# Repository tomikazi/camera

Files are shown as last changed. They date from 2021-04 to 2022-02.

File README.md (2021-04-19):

# Overview
The project provides a high-quality and low-latency video stream using Raspberry Pi HQ camera while allowing control of 
the camera orientation on pan & tilt axes. The video stream can be viewed using any modern browser or mobile device.
The camera orientation can be controlled using several different means. On mobile devices, it can be controlled using
touch swipe gestures or by moving the mobile device in 3D space. On desktop or laptop computers, the keyboard or mouse
drag gestures can be used.



The project is an adaptation of the [131/h264-live-player](https://github.com/131/h264-live-player) project. It differs
from the original project in number of ways, with the most important distinction being that the camera code is structured
as a client that connects to a broker, which is capable of brokering connections to multiple cameras and allows
multiple viewers to view the same camera.

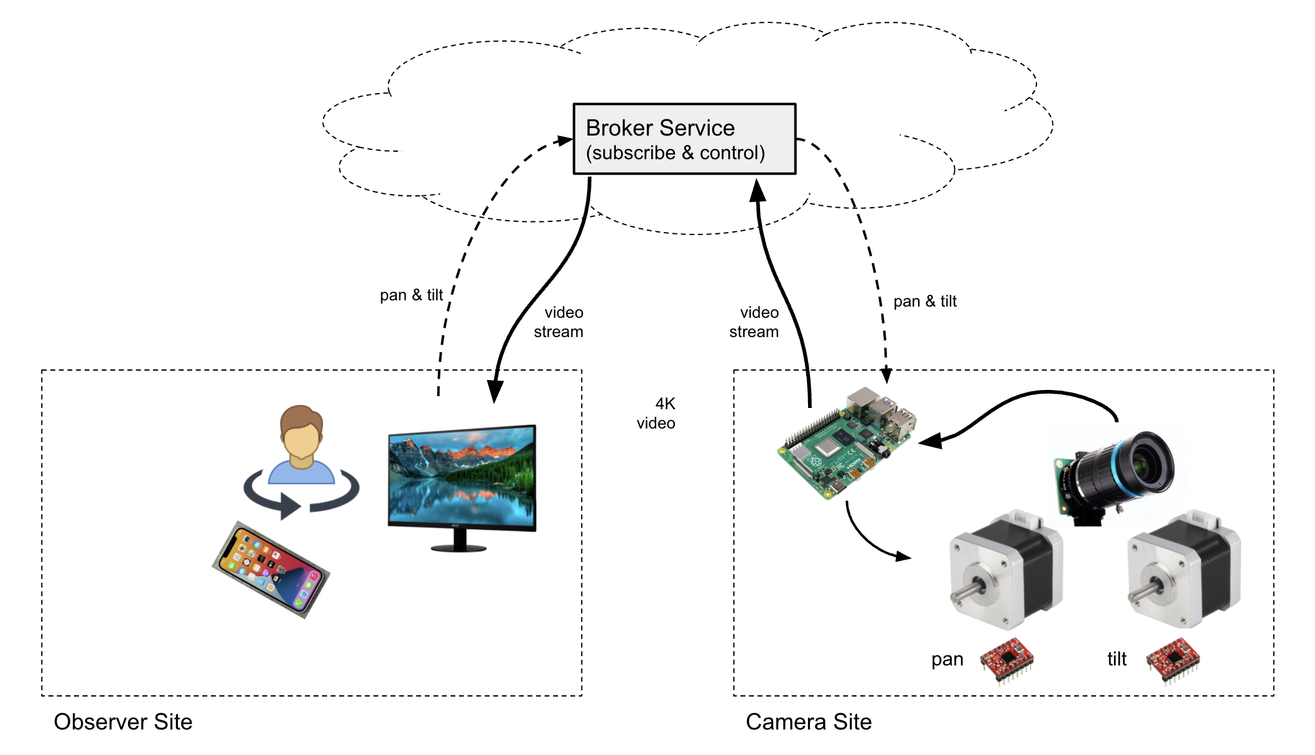
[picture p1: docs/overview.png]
Overview


This arrangement is better suited for deployment of cameras behind firewalls.

The video stream from the camera can be viewed on any modern browser. The pan/tilt can be controlled using several 
different means.

* Using mouse click-and-drag or tap-and-drag on touch devices
* Using arrow keyboard keys and other keyboard short-cuts  
* Using mobile device motion - works for iOS devices and select Androids that support `DeviceMotionEvent` Web API
    * Note that this requires the broker to use HTTPS

The pan and tilt mechanism uses A4988 stepper drivers and NEMA 17 motors to move about a Raspberry Pi HQ camera.
The current mount design allows for -180/+180 degrees on pan axis and -50/+50 degrees on tilt axis. Two hall-effect
sensors are used as limit sensors to allow for auto-homing the mount.

Note that this adaptation mangles the original by removing the alternate forms of streaming, instead focusing
solely on supporting the `raspvid` live stream.

# Installation of Broker Software
The broker is required as it is the only means of acquiring the video stream. For simple setup, it can be installed on
the same Raspberry Pi as the camera software. 

```
# Install or update the camera broker software
curl -s https://raw.githubusercontent.com/tomikazi/camera/master/tools/install-broker.sh | sh

# Setup the camera broker software to run as a daemon
curl -s https://raw.githubusercontent.com/tomikazi/camera/master/tools/install-broker-service.sh | sudo sh
```

Once started, the broker will listen on port 6000 for incoming WebSocket connections from the cameras and on port 5000 
for incoming HTTP requests and WebSocket connections from viewers. To expose HTTPS, it's probably easiest to use Apache 2
and setup redirect using URL re-writing. (_TODO: Add docs on this_)

# Installation of Camera Software
Use the following steps to install or update the camera software:

```
# Install or update the camera software
curl -s https://raw.githubusercontent.com/tomikazi/camera/master/tools/install-camera.sh | sh

# Setup the camera software to run as a daemon
curl -s https://raw.githubusercontent.com/tomikazi/camera/master/tools/install-camera-service.sh | sudo sh -s CAMERA-NAME [BROKER-URL]
```

Once started, the software will trigger auto-homing sequence and attempt WebSocket connection on port 6000 to the broker.
After the connection is established, the `raspivid` will be spawned and its video stream will be sent over the WebSocket
to the broker, from where it can be sent to the current viewers, be recorded or processed in some manner.

# Simple Token Authorization
The broker supports a simple token-based authorization scheme that allows securing access to the camera streams so that
only the users that know the camera name and a valid access token can access the video stream.

To enable the scheme, create a `tokens` file in the directory where the broker is installed. The format of the file
is as follows:

```
# userName: cameraName token
tom: FrontYard c11559d8-e91c-4140-85f0-9e14b4744e7e
tom: BackYard 329f1a1b-5c8d-40ab-9148-434f84312821
tom: Driveway 7a247b22-7bd8-4b27-8e1c-404fea90b615
guest: FrontYard 4ceb02b3-a0e9-4989-b1ff-72c3aac973ae
guest: Driveway a5217204-133d-4b39-900f-2222c962b535
```
The token is expected to be the standard 36 character UUID (see `uuidgen`). Presently, the user name is not used for
anything other than token management via the provided `ptcam-auth` script, which has the following usage:

```
usage: ptcam-auth <camera> list
       ptcam-auth <camera> <name>
       ptcam-auth <camera> grant <name>
       ptcam-auth <camera> revoke <name>
```

# Launching Viewer
To view a particular camera video stream, simply connect to the broker URL on port 5000 and specify the camera name and 
if security is required, the camera token, e.g.:

```
http://192.168.1.79:5000/camera/?id=FrontYard&t=c11559d8-e91c-4140-85f0-9e14b4744e7e
```

This will provide the web-page with the video stream canvas. The following is an example of the GUI when viewed on an
iOS device and with the camera positions shortcut menu activated:

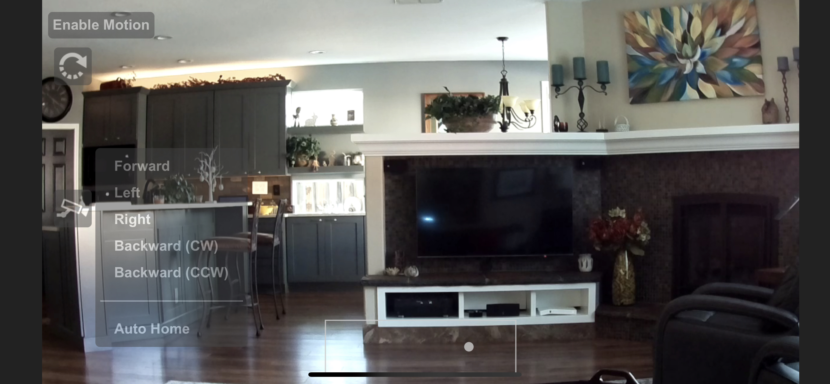
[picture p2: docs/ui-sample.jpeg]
Camera UI


The pan/tilt position and range indicator box is shown at the bottom and will be visible only when the camera is in motion.
You can see a brief [demo of the camera operation on YouTube](https://youtu.be/4mN1LiofYqg).

# REST API
The broker also supports a simple [REST API](/docs/api.md) using which other applications can query and control the remote cameras.

# Design
Additional design documentation for the 3D-printed mount, custom PCB and overall assembly can is available in the [Design](docs/design.md) section

# Credits to the original h264 project authors
* [131](mailto:131.js@cloudyks.org)
* [Broadway](https://github.com/mbebenita/Broadway)
* [urbenlegend/WebStreamer](https://github.com/urbenlegend/WebStreamer)

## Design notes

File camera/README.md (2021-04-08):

# Overview

This is an adaptation of the original h264 video player to provide a real-time (or at least low-latency) 
video stream a camera on a pan/tilt mount to a browser-based viewer. The viewer can be a mobile device
which when physically moved will result in corresponding motions of the pan/tilt mount. Alternatively,
when viewed from a computer or other devices that do not support `DeviceMotionEvent` Web API the user
can control pan/tilt by dragging the orientation indicator within the pan/tilt range box.

This adaptation mangles the original by removing the alternate forms of streaming, instead focusing
directly only on the `raspvid` live stream.  The pen tilt mechanism uses A4988 stepper drivers to mount 
and move about a Raspberry Pi HQ camera.

# Motivation
_The following are the original notes._

This is a very simple h264 video player (that can run on live stream) for your browser.
You might use this with raspicam raw h264 stream.
This is a player around [Broadway](https://github.com/mbebenita/Broadway) Decoder, with very simple API.
NAL unit (h264 frames) are split on the server side, transported using websocket, and sent to the decoded (with frame dropping, if necessary)




# History
* I was targetting a real-time camera video feedback (no audio/surveillance cam) in the browser
* There is no solution for "real time" mp4 video creation / playback (ffmpeg, mp4box.js, mp4parser - _boxing_ _takes_ _time_)
* Media Source Extension is a dead end (mp4 boxing is far too hard to re-create on the client side)
* [Broadway](https://github.com/mbebenita/Broadway) provide the crazy emscripten/asm build of a h264 decoder accelerated by webGL canvas
* Here is all the glue we need, enjoy ;-)

# Installation/demo
```
git clone git@github.com:131/h264-live-player.git player
cd player
npm install

node server-rpi.js    # run on a rpi for a webcam demo
node server-static.js # for sample video (static) file delivery
node server-tcp.js    # for a remote tcp (rpi video feed) sample
node server-ffmpeg    # usefull on win32 to debug the live feed (use ffmpeg & your directshow device / webcam) 

# browse to http://127.0.0.1:8080/ for a demo player

```

# Recommendations
* Broadway h264 Decoder can only work with **h264 baseline profile**
* [**Use a SANE birate**](https://www.dr-lex.be/info-stuff/videocalc.html)
* Browserify FTW
* Once you understand how to integrate the server-side, feel free to use [h264-live-player](https://www.npmjs.com/package/h264-live-player) npm package in your client side app (see vendor/)
* Use [uws](https://github.com/uWebSockets/uWebSockets) (instead of ws) as websocket server

# Credits
* [131](mailto:131.js@cloudyks.org)
* [Broadway](https://github.com/mbebenita/Broadway)
* [urbenlegend/WebStreamer](https://github.com/urbenlegend/WebStreamer)

# Keywords / shout box
raspberry, mp4box, h264, nal, raspivid, mse, media source extension, iso, raspicam, bitrate, realtime, video, mp4, ffmpeg, websocket, ws, socket.io "Let's have a beer and talk in Paris"

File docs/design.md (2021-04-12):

# Design 

## BOM
The following list of materials is required to assemble the camera setup:

* Raspberry Pi 4B
* Raspberry HQ Camera
* 30-50cm Raspberry Camera ribbon cable
* 1 NEMA 17 pancake motor for tilt axis
* 1 NEMA 17 motor for pan axis
* 2 A4988 stepper drivers
* 12V 3-5Amp power supply
* Buck converter (for 12V DC to 5V DC)
* 2 hall effect sensors (for limit switches)
* 2 10K resistors (for limit switches)
* 2 6mm neodymium magnets (for limit switches)
* 3D printed mount (Fusion 360 & STL files available below)
* Custom driver board and header board (Eagle and Gerber files available below)
* 13 pixel long WS2812B 60/m strand (for LED illumination and viewer indicator)    
* ~1m shielded 28AWG 3-wire cable (for limit switch cables)
* ~10cm 10-wire ribbon cable (for driver board to header board connection)
* 2 x ~60cm 4-wire stepper motor cables (may come with NEMA motors)
* ~70cm of ¼ nylon braided cable sleeving
* 4x M2.5x3-4mm screws (for securing buck converter and driver board)
* 8x 12-14mm rubber feet (4 for enclosure and 4 fo camera base)

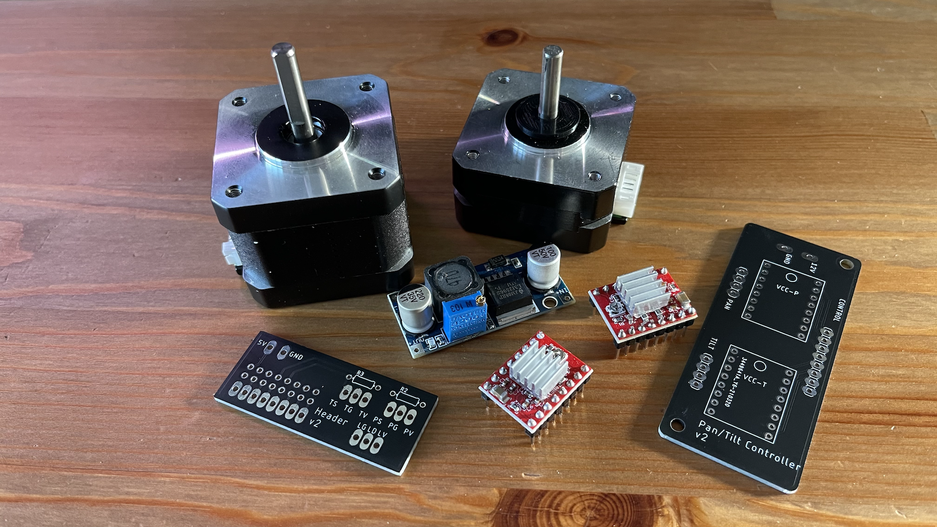
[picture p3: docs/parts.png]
Parts


## Mount and Enclosure Design
The enclosure case and the various parts of the mount itself were all custom designed from scratch using Autodesk Fusion 360. 
The objective was to make it as simple and modular as possible, while also making it reasonably compact.

The following is a list of parts together with links to the STL and the original Fusion design files:

#### Enclosure - [Fusion 360 File](../design/fusion360/PanTiltEnclosure%20v17.f3z)
* Enclosure bottom
* Enclosure top

#### Mount Assembly] - [Fusion 360 File](../design/fusion360/PanTiltMechanism%20v32.f3d)
* Pan motor mount
* Tilt motor mount
* Camera mount
* Camera plate
* Camera back plate ([design from Thingiverse](https://www.thingiverse.com/thing:4540545))
* Camera back clip
* Pan axle washer

## Electronics
A pair of simple PCBs was designed to allow for relatively simple assembly. The boards were designed using Autodesk Eagle.
Below are links to their schematic and board design files for Autodesk EAGLE:

The two boards are:
* Stepper Driver board for housing the two A4988 stepper drivers - [PCB](../design/eagle/PanTiltCtlBoard.brd) - [Schematic](../design/eagle/PanTiltCtlBoard.sch)
    * +12V/GND pads
    * 2 A4988 drivers (pan/tilt)
    * 8-pin header for harness connection to the Raspberry Pi header board

* Header break-out board for connecting to the top 16 GPIO pins of the Raspberry Pi - [PCB](../design/eagle/PanTiltHeader.brd) - [Schematic](../design/eagle/PanTiltHeader.sch)
    * 8 pads for harness interconnect with the stepper driver
    * +5V/GND to power Raspberry Pi
    * +3V3/GND/DATA pads for pan limit switch
    * +3V3/GND/DATA pads for tilt limit switch
    * +5V/GND/DATA pads for LED strip
  
The design folder also has ZIP files for ordering the PCBs on JLCPCB.

## Wiring Harnesses

* Motor Cables
    * Tilt: 56cm
    * Pan: 39cm
* Limit Sensor Cables
    * Tilt: 48cm
    * Pan: 25cm
* Sleeves for Cables
    * Tilt: 44cm
    * Pan: 20cm
* Header Ribbon Cable (8-wide)
    * 10cm
* LED Cable (5V/GND/Data)
    * 35cm

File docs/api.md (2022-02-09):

# REST API

Other applications can use the following REST API to query and control the remote cameras.

* `GET /camera/api/cameras`
    * returns array of currently registered camera names
* `GET /camera/api/viewers`
    * returns array of objects with camera name and the viewer remote address
* `GET /camera/api/:camera`
    * returns current camera position and any remote viewers
* `GET /camera/api/:camera/snapshot`
    * takes a snapshot and returns PNG image data
* `GET /camera/api/:camera/recordings`
    * returns an array of current recording files
* `GET /camera/api/:camera/recordings/:recording`
    * returns the specified recording as raw H.264 file
* `PUT /camera/api/:camera`
    * issues command to the specified camera, `setHome`, `moveTo`, `moveBy`, `snap`, `startRecording`, `stopRecording`
    * `moveTo` takes either `pos` set to `home`, `F`, `L`, `R`, `U`, `D`, `UL`, `UR`, `DL`, `DR` or `pan` and `tilt` coordinates
       * `duration` specifies number of milliseconds for the move to take
       * `ease` can be set to `linear`, `quad` or `cubic` to for specific easing function; default is `quad`
    * `moveBy` takes `pan` and `tilt` steps relative to current position
    * `setHome` records the current position as the default home
    * `startRecording`/`stopRecording` starts/stops recording of video to disc
* `DELETE /camera/api/:camera/:viewerIP`
    * disconnects all viewers from the specified IP address on the given camera; this can be used
      after revoking a token
      
## Authorization
If token authorization is enabled, the HTTP request must have the `token` header populated
with a valid camera token. Any camera token can be used to obtain the list of cameras or the list of viewers,
but any camera-specific request must have camera-specific `token` provided.

# Examples
The following are a few examples of how one might use the `curl` command to issue API requests:
```
# Get list of all cameras
curl -H 'Content-type: application/json' -H 'token: 340d1b94-9bd4-893f-49ef-4c772132ce06' \
    http://broker.local:5000/camera/api/cameras
["Driveway", "FrontYard", "BackYard"]

# Get information about front yard camera
curl -H 'Content-type: application/json' -H 'token: 340d1b94-9bd4-893f-49ef-4c772132ce06' \
    http://broker.local:5000/camera/api/FrontYard
{
  "camera": "FrontYard",
  "viewers": [
    "::ffff:192.168.1.71"
  ],
  "pos": {
    "pan": -438,
    "tilt": 219
  }
}

# Pan all the way to the right position; tilt level at 0; take 1 second and use cubic easing function to govern the move
curl -H 'Content-type: application/json' -H 'token: 340d1b94-9bd4-893f-49ef-4c772132ce06' \
    -X PUT http://broker.local:5000/camera/api/FrontYard -d '{ "cmd": "moveTo", "pos": "R", "duration": 1000, "ease": "cubic" }'

# Pan to specific coordinates in 500ms using default easing function
curl -H 'Content-type: application/json' -H 'token: 340d1b94-9bd4-893f-49ef-4c772132ce06' \
    -X PUT http://broker.local:5000/camera/api/FrontYard -d '{ "cmd": "moveTo", "pan": -50, "tilt": 10, "duration": 500 }'

# Move left (counter-clockwise) and upward relative to the current orientation
curl -H 'Content-type: application/json' -H 'token: 340d1b94-9bd4-893f-49ef-4c772132ce06' \
    -X PUT http://broker.local:5000/camera/api/FrontYard -d '{ "cmd": "moveBy", "pan": -30, "tilt": 20 }'

```

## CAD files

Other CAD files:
design/fusion360/PanTiltMechanism v32.f3d

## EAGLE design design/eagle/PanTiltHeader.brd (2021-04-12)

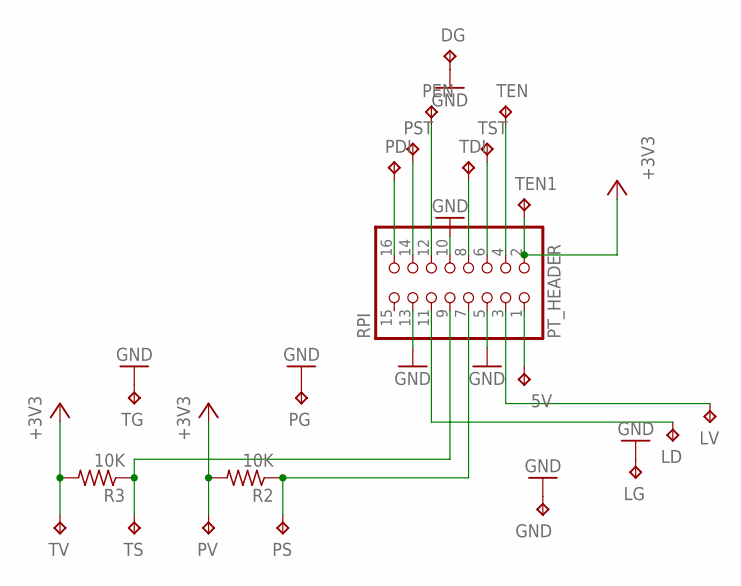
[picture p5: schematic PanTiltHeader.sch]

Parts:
5V: TPPAD1-13Y; P1-13Y
DG: TPPAD1-13Y; P1-13Y
GND: TPPAD1-13Y; P1-13Y
LD: TPPAD1-13Y; P1-13Y
LG: TPPAD1-13Y; P1-13Y
LV: TPPAD1-13Y; P1-13Y
PDI: TPPAD1-13Y; P1-13Y
PEN: TPPAD1-13Y; P1-13Y
PG: TPPAD1-13Y; P1-13Y
PS: TPPAD1-13Y; P1-13Y
PST: TPPAD1-13Y; P1-13Y
PT_HEADER: RPI; 2X08
PV: TPPAD1-13Y; P1-13Y
R2, R3: 10K; 0204/7
TDI: TPPAD1-13Y; P1-13Y
TEN, TEN1: TPPAD1-13Y; P1-13Y
TG: TPPAD1-13Y; P1-13Y
TS: TPPAD1-13Y; P1-13Y
TST: TPPAD1-13Y; P1-13Y
TV: TPPAD1-13Y; P1-13Y

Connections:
+3V3: PT_HEADER.2, PV.TP, R2.2, R3.2, TEN1.TP, TV.TP
GND: DG.TP, GND.TP, LG.TP, PG.TP, PT_HEADER.5, PT_HEADER.10, PT_HEADER.13, TG.TP
unnamed: PT_HEADER.4, TEN.TP
unnamed: PT_HEADER.6, TST.TP
unnamed: PT_HEADER.8, TDI.TP
unnamed: PT_HEADER.9, R3.1, TS.TP
unnamed: PEN.TP, PT_HEADER.12
unnamed: PST.TP, PT_HEADER.14
unnamed: PDI.TP, PT_HEADER.16
unnamed: 5V.TP, PT_HEADER.1
unnamed: LV.TP, PT_HEADER.3
unnamed: PS.TP, PT_HEADER.7, R2.1
unnamed: LD.TP, PT_HEADER.11

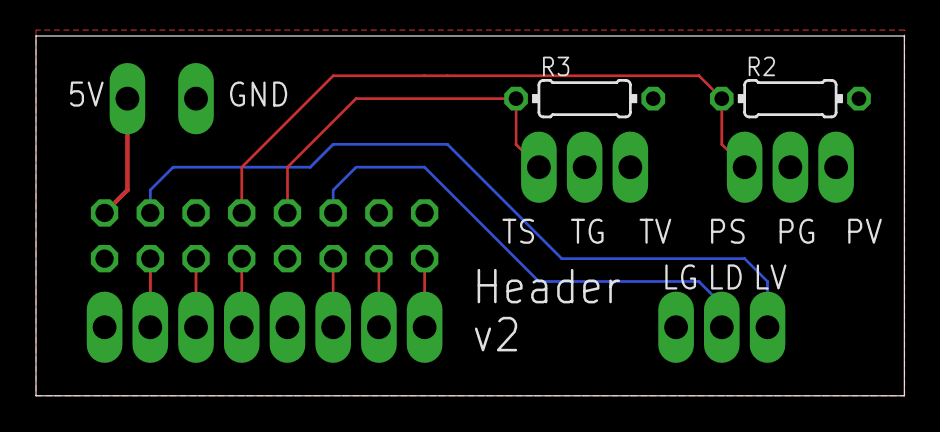
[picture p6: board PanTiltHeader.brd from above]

Board: 2 copper layers, 48.2 x 20.0 mm, 22 parts (1 on the bottom side), 13 nets.

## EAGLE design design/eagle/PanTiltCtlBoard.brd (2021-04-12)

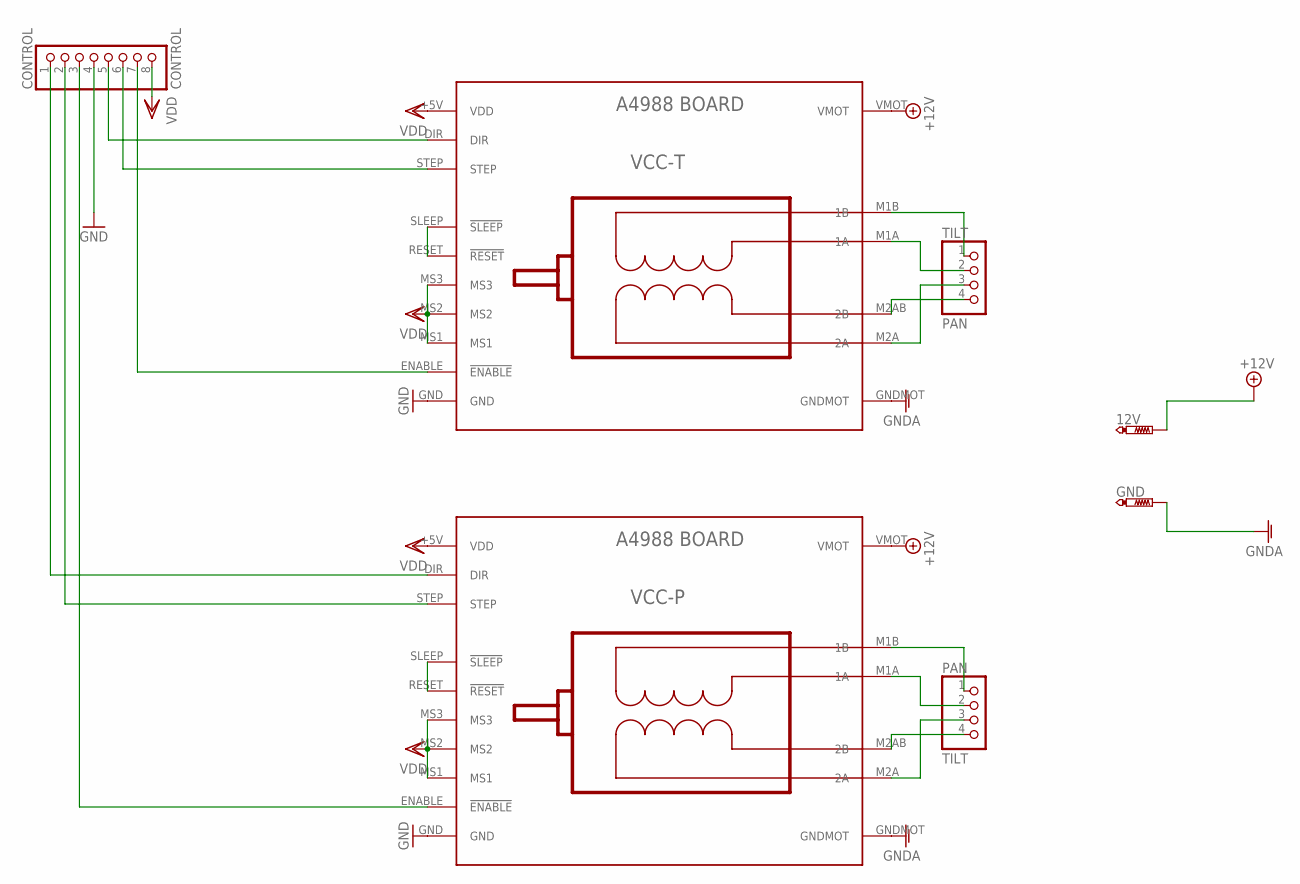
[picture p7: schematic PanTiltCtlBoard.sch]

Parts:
12V: PTR1PAD1-13Y; P1-13Y
CONTROL: CONTROL; 1X08
GND: PTR1PAD1-13Y; P1-13Y
PAN: TILT; 1X04
TILT: PAN; 1X04
VCC-P: BOARD_A4988
VCC-T: BOARD_A4988

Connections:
+12V: 12V.TP, VCC-P.VMOT, VCC-T.VMOT
GND: CONTROL.4, VCC-P.GND, VCC-T.GND
GNDA: GND.TP, VCC-P.GNDMOT, VCC-T.GNDMOT
unnamed: TILT.4, VCC-T.M2AB (2B)
unnamed: VCC-T.RESET (!RESET), VCC-T.SLEEP (!SLEEP)
unnamed: CONTROL.7, VCC-T.ENABLE (!ENABLE)
unnamed: CONTROL.6, VCC-T.STEP
unnamed: CONTROL.5, VCC-T.DIR
unnamed: CONTROL.1, VCC-P.DIR
unnamed: CONTROL.2, VCC-P.STEP
unnamed: CONTROL.3, VCC-P.ENABLE (!ENABLE)
unnamed: VCC-P.RESET (!RESET), VCC-P.SLEEP (!SLEEP)
unnamed: TILT.3, VCC-T.M2A (2A)
unnamed: TILT.1, VCC-T.M1B (1B)
unnamed: TILT.2, VCC-T.M1A (1A)
unnamed: PAN.4, VCC-P.M2AB (2B)
unnamed: PAN.3, VCC-P.M2A (2A)
unnamed: PAN.1, VCC-P.M1B (1B)
unnamed: PAN.2, VCC-P.M1A (1A)
VDD: CONTROL.8, VCC-P.+5V (VDD), VCC-P.MS1, VCC-P.MS2, VCC-P.MS3, VCC-T.+5V (VDD), VCC-T.MS1, VCC-T.MS2, VCC-T.MS3

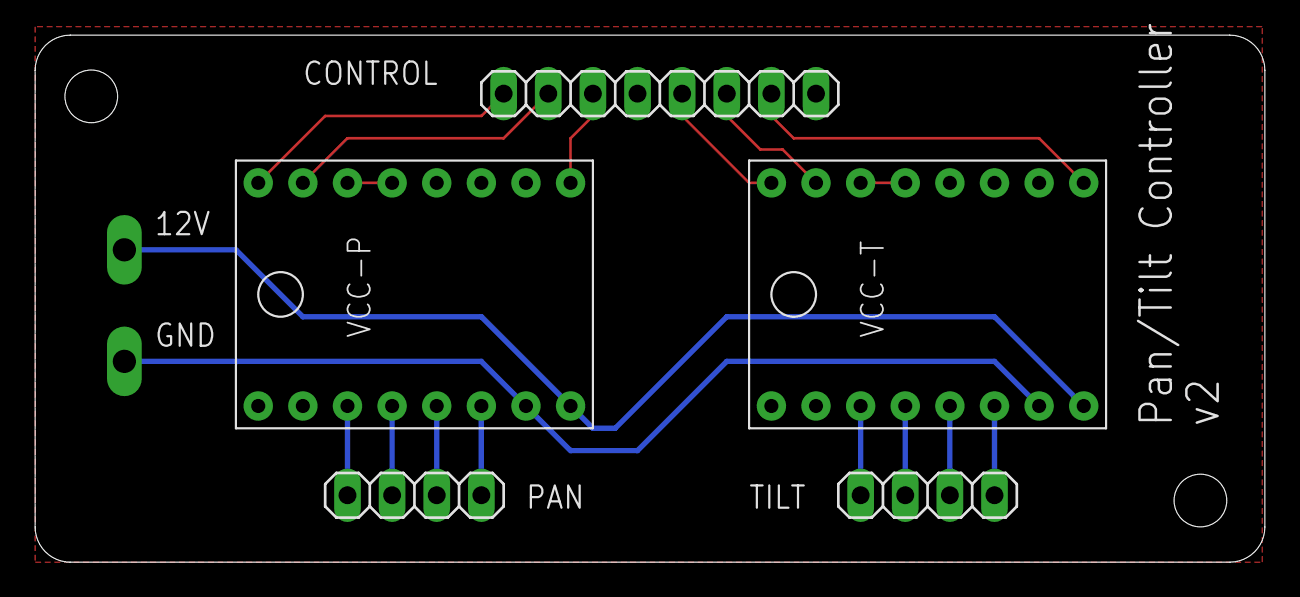
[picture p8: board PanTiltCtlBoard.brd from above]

Board: 2 copper layers, 70.0 x 30.0 mm, 7 parts (0 on the bottom side), 20 nets.

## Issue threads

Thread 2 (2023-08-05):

Questions Arising From Hardware Assembly

devinross, 2023-08-05:
There's some issues I'm seeing with how the hardware is all wired together. The documentation pages leaves a lot of holes to how everything is connected. I've listed the questions here below:

1. The 3 wire cables for pan and tilt that both connect to the Header board (TS, TG, TV, PS, PG, PV)… it’s unclear to me where these wires lead to / connect to. The 4 wires that lead off the motors lead to the Control board. I’m missing something here.
2. Assuming LG, LD, LV is for the LED strip?
3. The GPIO connection from the Raspberry PI to the Header board . Connecting to the PI was absent from the photos you sent, did you use a ribbon cable similar to this and just solder on one end to the header board? Curious how you attached those pins. (A cable like this with the pin slots? https://www.adafruit.com/product/4170)
4. What is the spec on the capacitor connected to the Control board? 1000 microfarad?

Diagram of my understanding:

https://www.icloud.com/freeform/0e6M6DNOYYXFfDh3A7Meg9VKA#Pan_and_Tilt_Camera_Diagram

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

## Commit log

2021-04-08 Renamed client to camera
2021-04-08 Adding install script for camera
2021-04-09 Added REST API for query and control of the cameras.
2021-04-09 Added ability to retain current camera position.
2021-04-10 Added photo of some of the part and custom boards.
2021-04-12 Added EAGLE files.
    [PanTiltCtlBoard.brd, PanTiltCtlBoard.sch, PanTiltHeader.brd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]
2021-04-12 Added Fusion 360 files.
    [PanTiltMechanism v32.f3d]
2021-09-22 Title the page using camera ID; disable motion when not 'https:'
2021-10-13 Added ability for broker to record the camera streams
2021-10-19 Added ability to record; extracting SPS, PPS and sync NAL frames
2022-02-01 Reworked to use servos instead of steppers to simplify HW setup
2022-02-01 Added ability to run camera client in no-video mode; only for pan/tilt control
2022-03-22 Adding ability to restart camera from viewer

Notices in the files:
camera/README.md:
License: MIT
